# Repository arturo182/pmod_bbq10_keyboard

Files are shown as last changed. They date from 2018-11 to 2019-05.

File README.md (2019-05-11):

# BB Q10 Keyboard PMOD

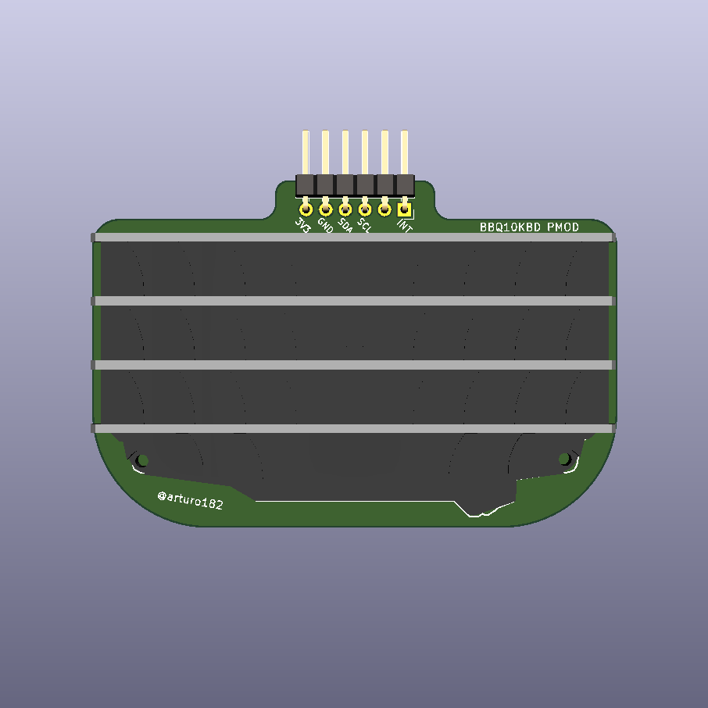
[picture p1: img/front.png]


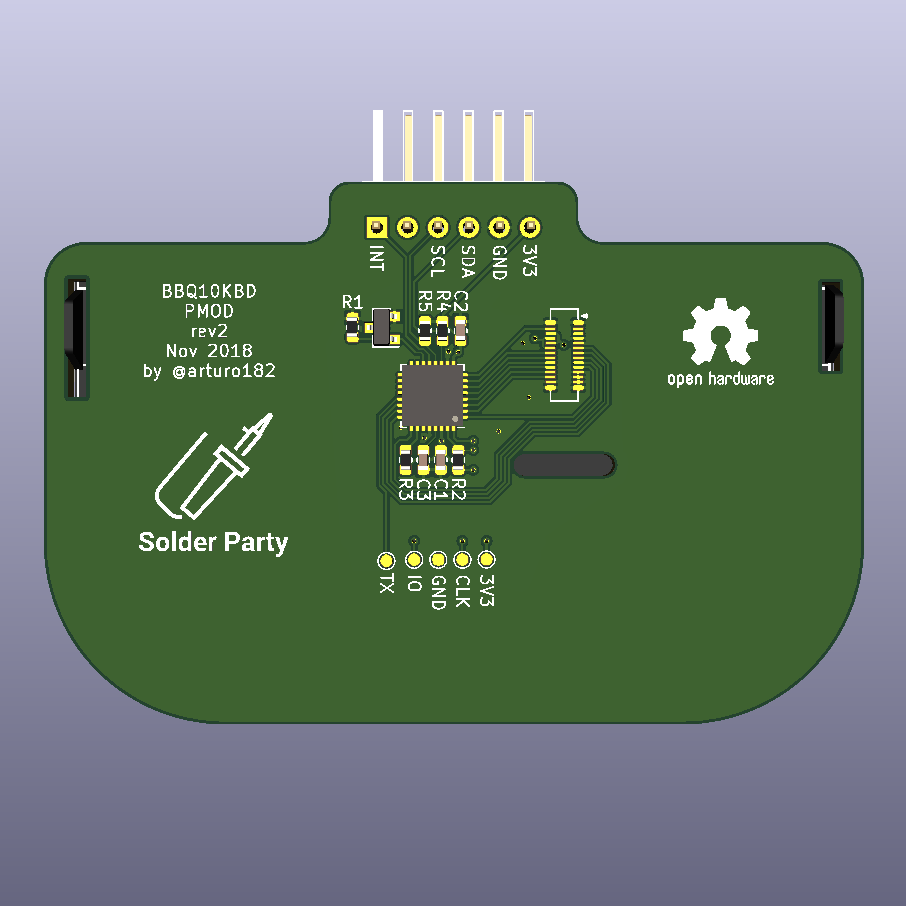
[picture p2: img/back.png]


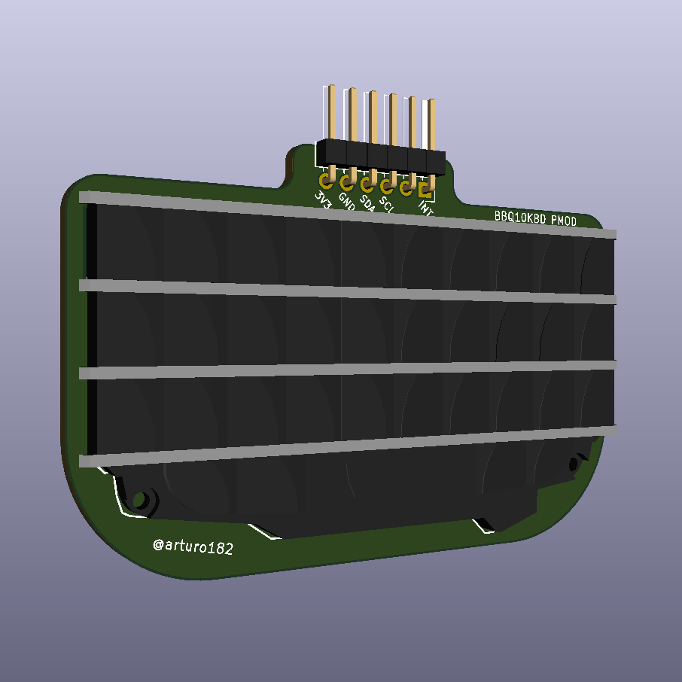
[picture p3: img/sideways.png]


A BB Q10 Keyboard in PMOD format!

This board uses a ATSAMD20 chip as a i2c slave that can be polled to get the key FIFO, the firmware for the SAM can be found here: https://github.com/arturo182/bbq10kbd_i2c_sw

The SAM chip also controls the backlight of the keyboard, the backlight brightness can be controlled over I2C as well.

A kernel module for the Raspberry Pi is available here: https://github.com/arturo182/bbq10pmod_module

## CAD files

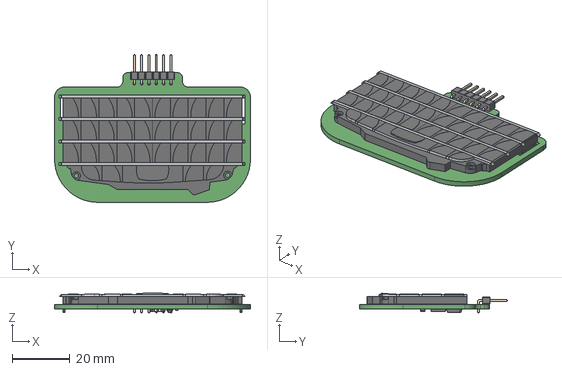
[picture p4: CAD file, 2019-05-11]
bbq10_keyboard.step
68.0 x 51.2 x 6.81 mm

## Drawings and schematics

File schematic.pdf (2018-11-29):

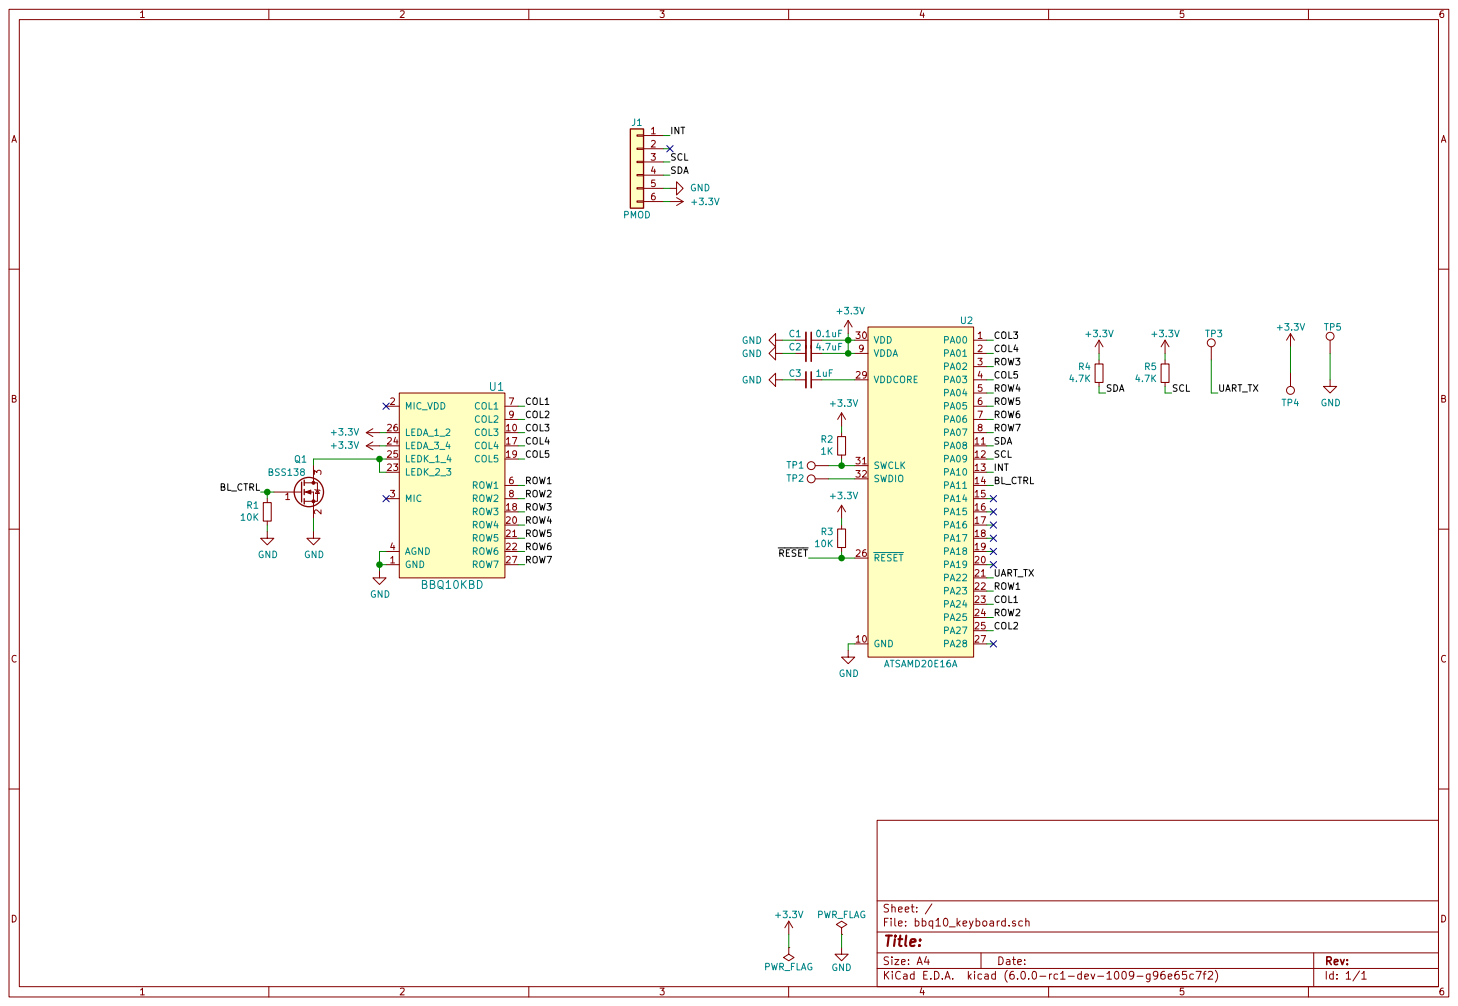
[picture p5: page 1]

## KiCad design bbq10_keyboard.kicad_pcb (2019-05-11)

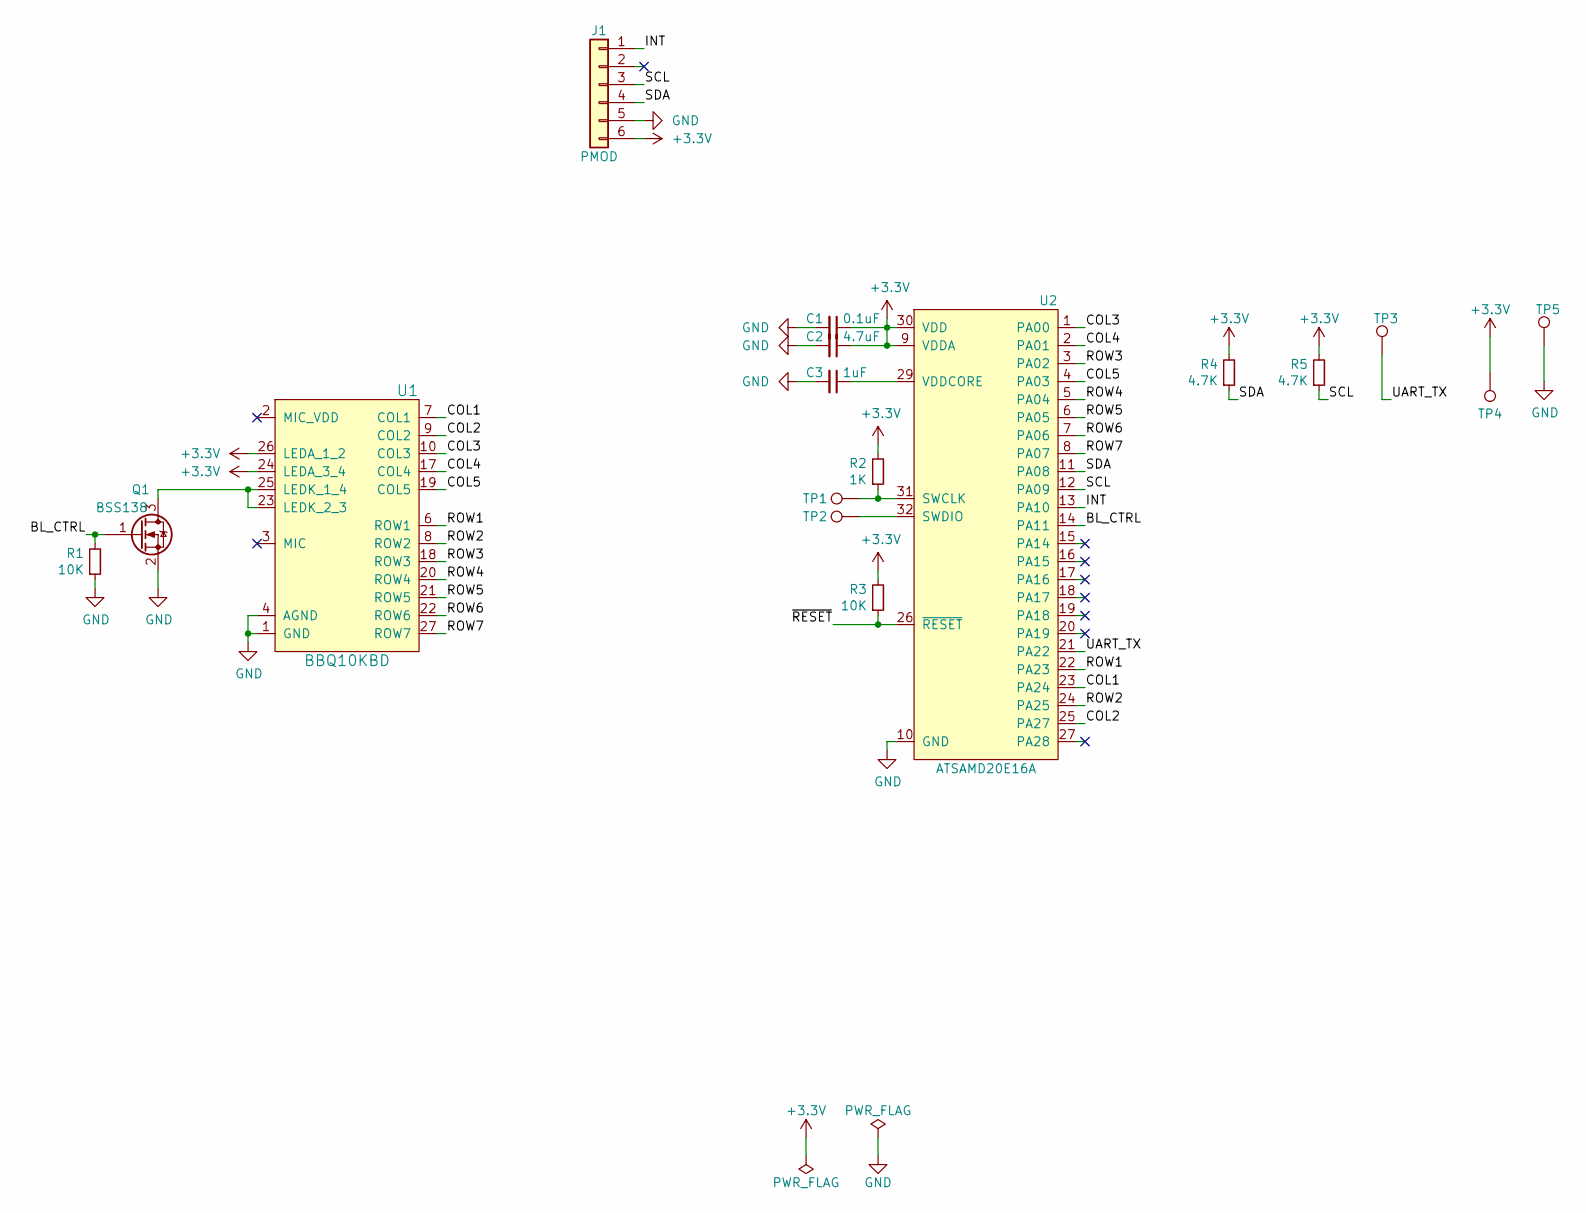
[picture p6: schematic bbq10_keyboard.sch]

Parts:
C1: 0.1uF; C_0603_1608Metric
C2: 4.7uF; C_0603_1608Metric
C3: 1uF; C_0603_1608Metric
J1: PMOD; PMODPinHeader_1x06_P2.54mm_Horizontal
Q1: BSS138; SOT-23
R1, R3: 10K; R_0603_1608Metric
R2: 1K; R_0603_1608Metric
R4, R5: 4.7K; R_0603_1608Metric
TP1: TP_SWCLK; TestPoint_Pad_D1.0mm
TP2: TP_SWDIO; TestPoint_Pad_D1.0mm
TP3: UART_TX; TestPoint_Pad_D1.0mm
TP4: VDD; TestPoint_Pad_D1.0mm
TP5: GND; TestPoint_Pad_D1.0mm
U1: BBQ10KBD; BM14B(0.8)-24DS-0.4V(53)
U2: ATSAMD20E16A; QFN-32-1EP_5x5mm_P0.5mm_EP3.45x3.45mm

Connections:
+3V3: C1.1, C2.1, J1.6, R2.2, R3.2, R4.2, R5.2, TP4.1, U1.24 (LEDA_3_4), U1.26 (LEDA_1_2), U2.9 (VDDA), U2.30 (VDD)
/BL_CTRL: Q1.1 (G), R1.2, U2.14 (PA11)
/COL1: U1.7 (COL1), U2.23 (PA24)
/COL2: U1.9 (COL2), U2.25 (PA27)
/COL3: U1.10 (COL3), U2.1 (PA00)
/COL4: U1.17 (COL4), U2.2 (PA01)
/COL5: U1.19 (COL5), U2.4 (PA03)
/INT: J1.1, U2.13 (PA10)
/ROW1: U1.6 (ROW1), U2.22 (PA23)
/ROW2: U1.8 (ROW2), U2.24 (PA25)
/ROW3: U1.18 (ROW3), U2.3 (PA02)
/ROW4: U1.20 (ROW4), U2.5 (PA04)
/ROW5: U1.21 (ROW5), U2.6 (PA05)
/ROW6: U1.22 (ROW6), U2.7 (PA06)
/ROW7: U1.27 (ROW7), U2.8 (PA07)
/SCL: J1.3, R5.1, U2.12 (PA09)
/SDA: J1.4, R4.1, U2.11 (PA08)
/UART_TX: TP3.1, U2.21 (PA22)
/~RESET~: R3.1, U2.26 (~RESET~)
GND: C1.2, C2.2, C3.2, J1.5, Q1.2 (S), R1.1, TP5.1, U1.1 (GND), U1.4 (AGND), U1.5 (GND), U1.11 (GND), U1.12 (GND), U1.13 (GND), U1.14 (GND), U1.15 (GND), U1.16 (GND), U1.28 (GND), U2.10 (GND), U2.28 (GND)
unnamed: C3.1, U2.29 (VDDCORE)
unnamed: Q1.3 (D), U1.23 (LEDK_2_3), U1.25 (LEDK_1_4)
unnamed: R2.1, TP1.1, U2.31 (SWCLK)
unnamed: TP2.1, U2.32 (SWDIO)

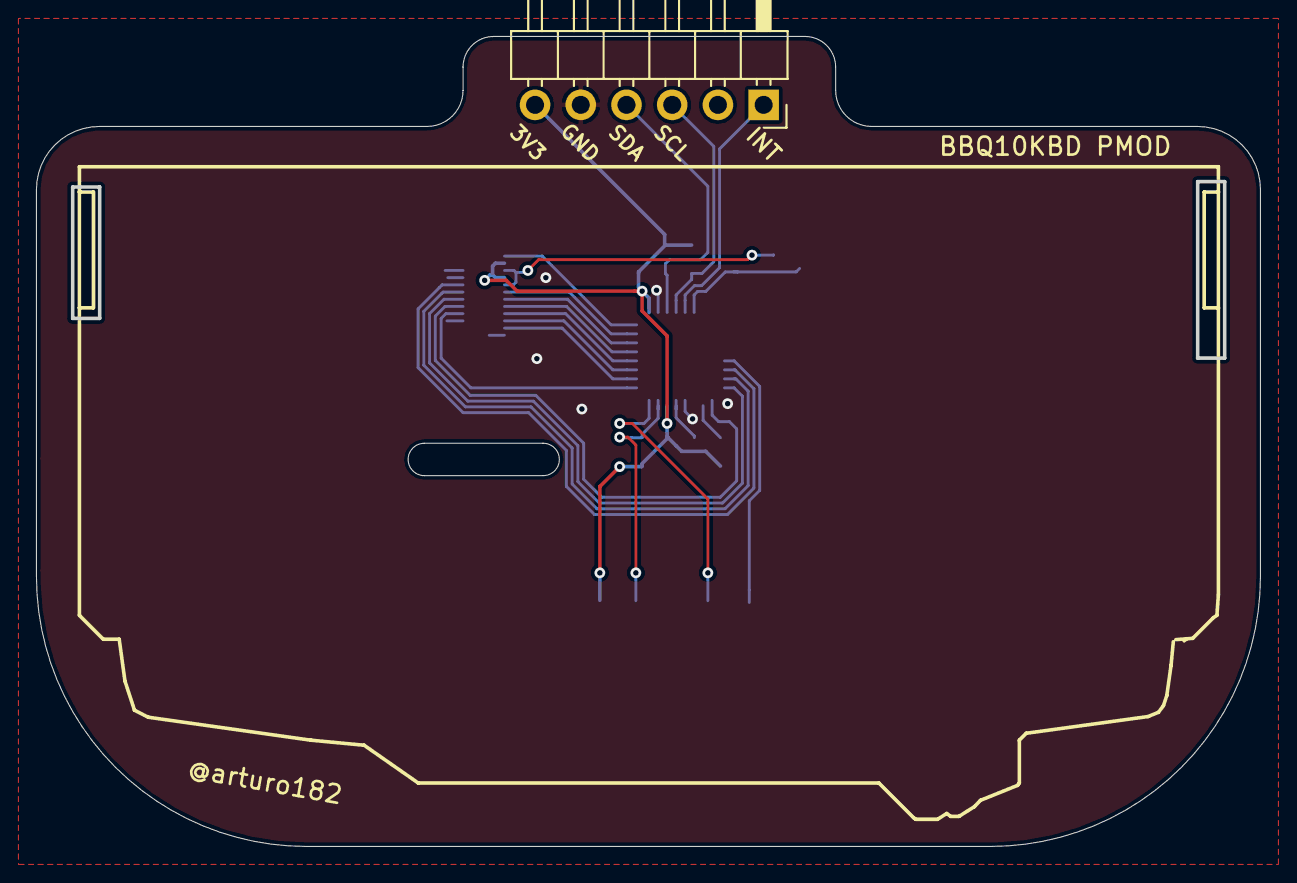
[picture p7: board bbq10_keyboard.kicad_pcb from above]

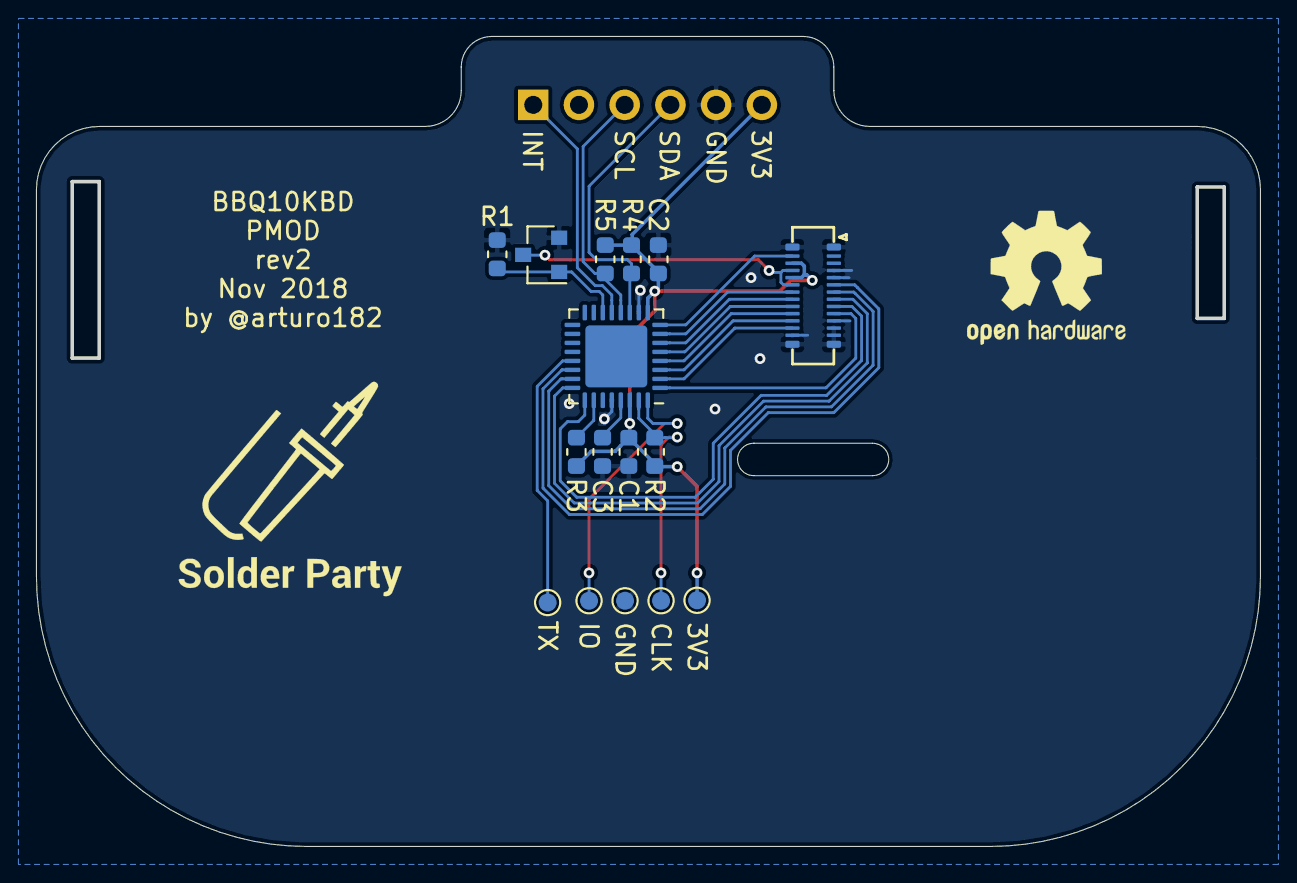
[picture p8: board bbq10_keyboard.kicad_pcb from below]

Board: 2 copper layers, 68.0 x 45.0 mm, 17 parts (16 on the bottom side), 24 nets.

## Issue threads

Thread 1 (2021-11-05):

How to bend the Flex PCB?

Dakkaron, 2021-11-05:
I am trying to build something similar (a keyboard attachment for my phone) but I can't figure out how to safely bend the flex PCB in a way that I have the connector somewhere else than on the phone screen.

How did you move the connector to where you put it?

arturo182, 2021-11-05:
It's quite hard to explain but hopefully, these photos show it well enough. The flex is bent onto itself quite harshly, but the keyboard and the flex are held in place with double-sided tape so they are not moving at all.

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

I have another board using this keyboard (https://github.com/solderparty/keyboard_featherwing_hw) and since that one is larger, there is no need to bend the flex, I follow the natural shape of the flex, just go from one side of the board to the other and put a connector where it ends:
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

Dakkaron, 2021-11-05:
Awesome! Thanks for the great description and the pictures!
My solution will probably have even less space than your original one, so I'd probably take the same route.
I just couldn't figure out whether the flex PCB would survive such a harsh bend, and wanted to take your work as an example.

Thanks a lot!

Closed 2021-11-05.

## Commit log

2018-11-25 Initial import
    [bbq10_keyboard.kicad_pcb, bbq10_keyboard.sch]
2018-11-29 rev2
    - Made the right keyboard hole larger
    - Moved the conenctor to the back
    - Rerouted everything
    - Fixed the damn 0201 footprints
    [bbq10_keyboard.kicad_pcb, bbq10_keyboard.sch]
2018-11-29 Add schematic and update bom
2019-05-11 Moved ibom, renamed schematic, added 3D model
    [bbq10_keyboard.kicad_pcb, bbq10_keyboard.step]
